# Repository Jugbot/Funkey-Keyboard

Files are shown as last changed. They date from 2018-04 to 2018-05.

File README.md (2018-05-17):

# Funkey-Keyboard ヽ(⌐■_■)ノ♪♬
### A piano with a built-in rhythm game! 
This was a project for New York University's prototyping design class (EG1003) for spring of 2018. The design won the Nick Russo Award and the I2E Award for Innovation.  

The idea behind this prototype was to make learning the piano easier by turning it into a sort of rhythm game. Other similar solutions exist out there such as [pianos that light up the next keys](https://www.smartpiano.com/) or tablet apps that record audio from an existing piano and use it as an input for a a [game-like learning tool](https://www.synthesiagame.com/). This prototype is slightly different in that it integrates 8 leds directly under every key. There is also the possibility of modularity due to the chainable input and display. 

Check out the [video demonstration](https://youtu.be/wlrPzlZg1Dw).

| Implemented | <ul><li>Automatic conversion of midi files to playable songs</li><li>Real time playback</li><li>Pseudo-random color change for differentiating notes</li></ul> |
| :--- | :--- |
| Unimplemented | <ul><li>Tempo must be input manually (bpm variable in code)</li><li>The circuit board for the buttons failed, so input recording and scoring was not able to be tested</li><li>As such the menu with scrolling text is not used in the last release and songs must be set beforehand in-code</li></ul> |

---
## Basic Specs
+ Raspberry Pi 3
+ Python 2

---
## Dependencies:
+ pyllist
+ python-midi
+ adafruit-gpio

---
## Hardware
I used the [ws2811 addressable rgb led string](http://a.co/irZiaNd) as a display.

For the inputs I decided to use [mcp23017 io port expander](https://www.adafruit.com/product/732) to demonstrate the possibility of modularity. 

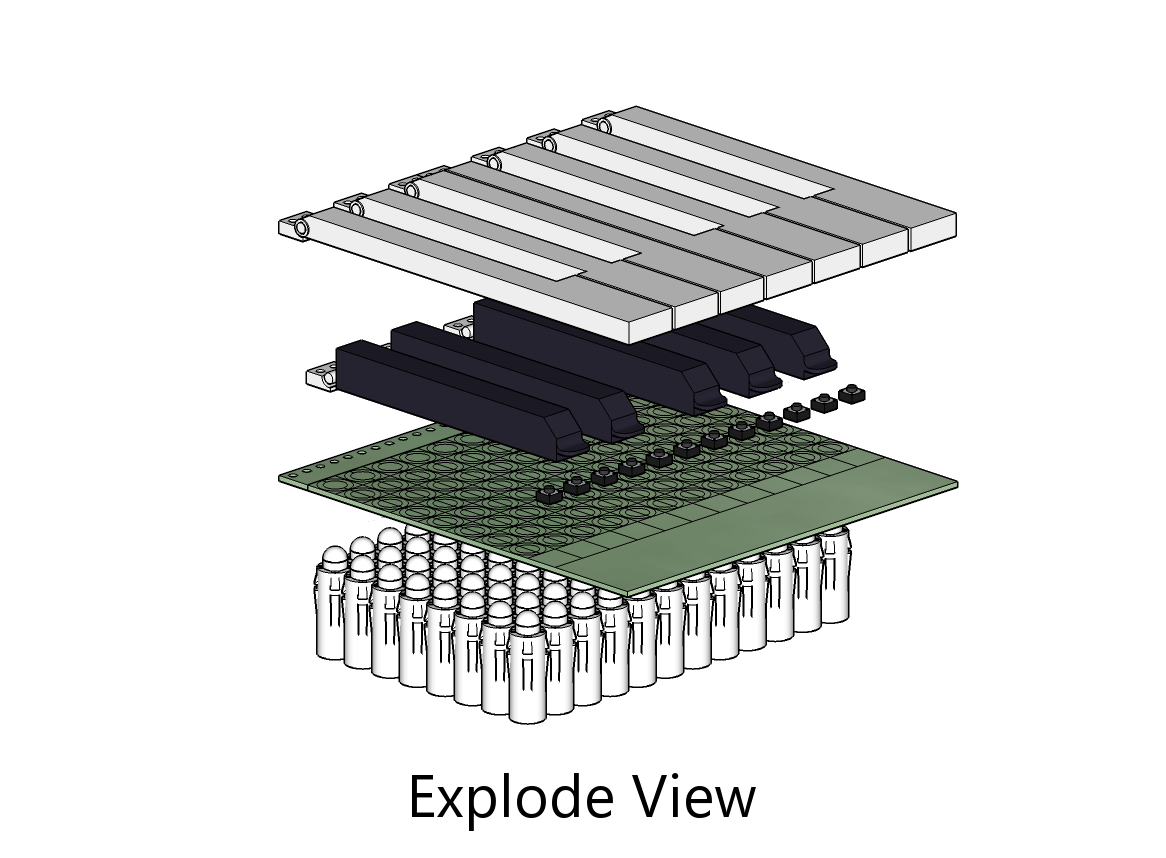
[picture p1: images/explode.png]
Image of ortho explode view


Button Input/ LED Mount | Electrical Schematic 
----------------------- | -------------------- 
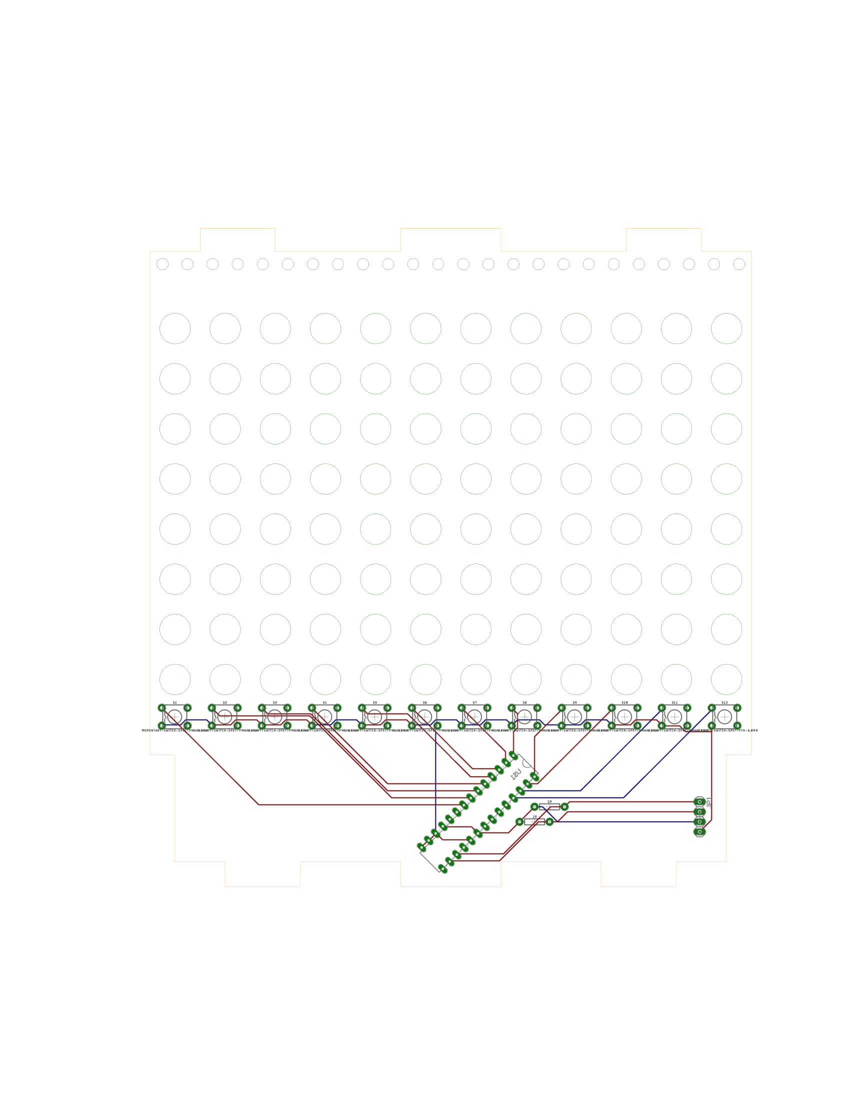
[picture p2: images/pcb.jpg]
Image of pcb board
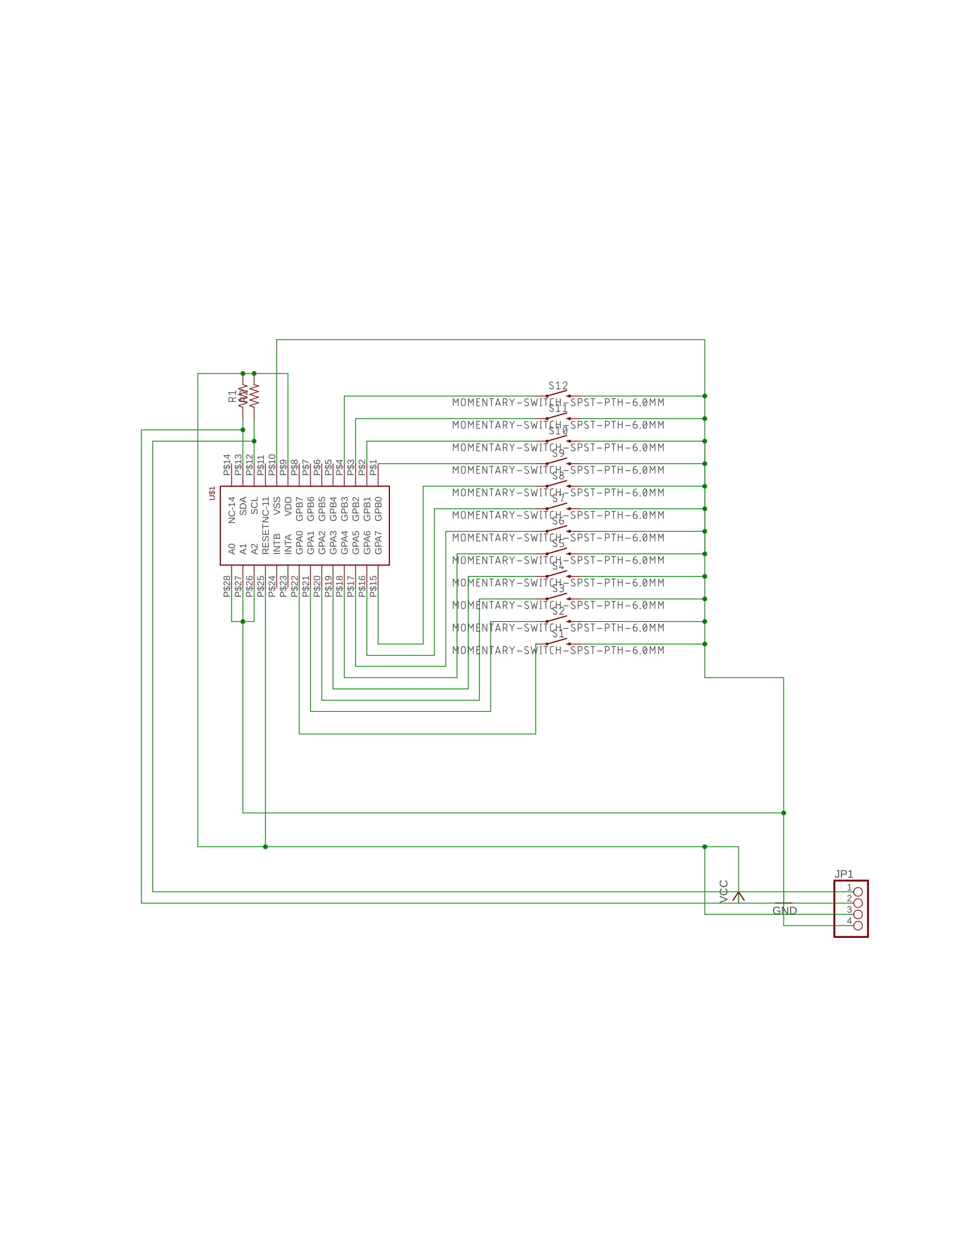
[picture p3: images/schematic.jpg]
Image of electrical schematic
 |

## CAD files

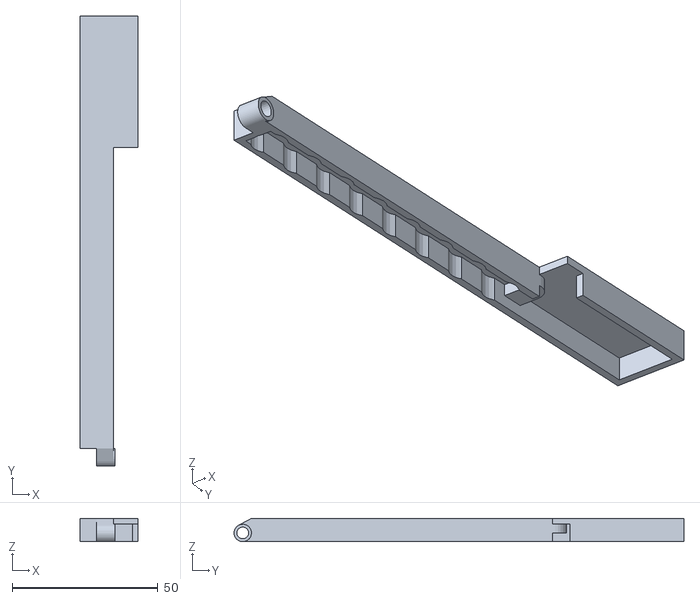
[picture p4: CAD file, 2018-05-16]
Technical Files/resin prints/ekey.stl
20.0 x 154.2 x 8.00

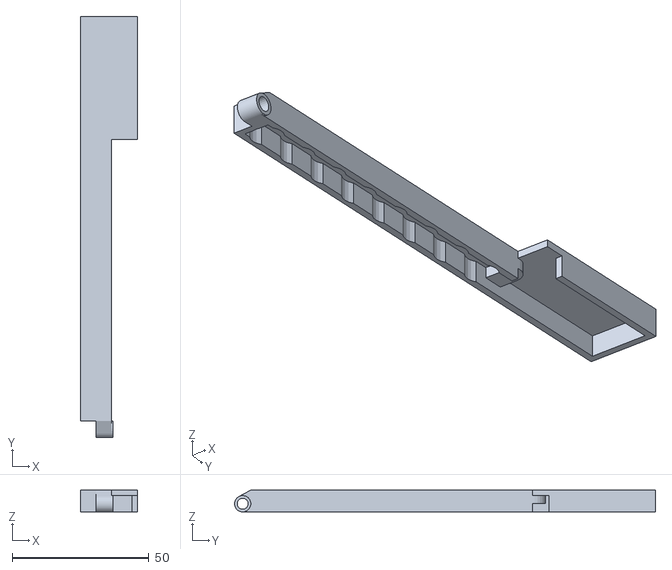
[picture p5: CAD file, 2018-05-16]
Technical Files/resin prints/bkey.stl
21.0 x 154.2 x 8.00

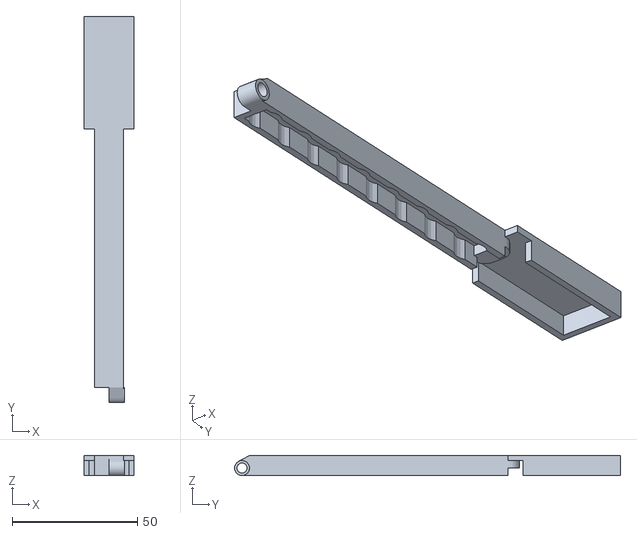
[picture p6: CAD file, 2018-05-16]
Technical Files/resin prints/dkey.stl
20.0 x 154.2 x 8.00

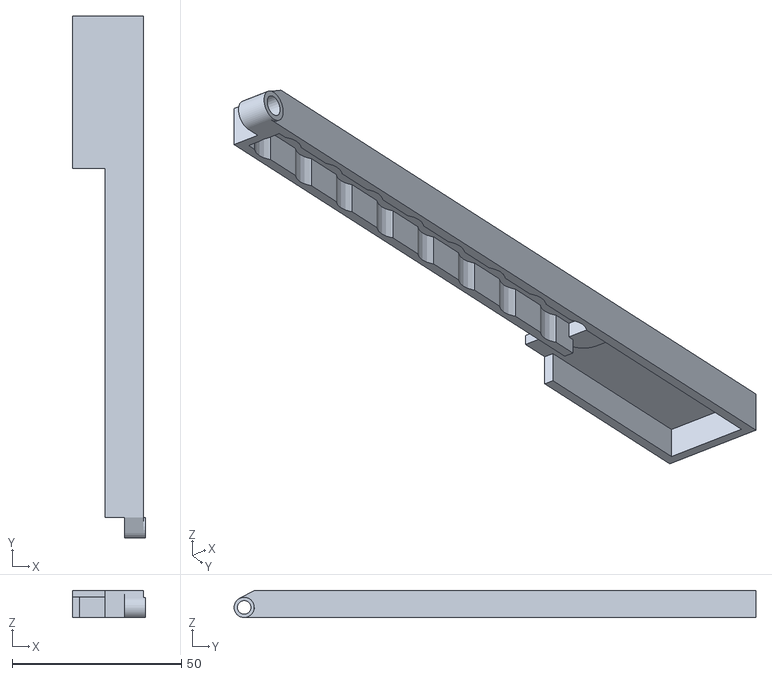
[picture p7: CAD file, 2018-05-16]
Technical Files/resin prints/fkey.stl
21.6 x 154.2 x 8.00

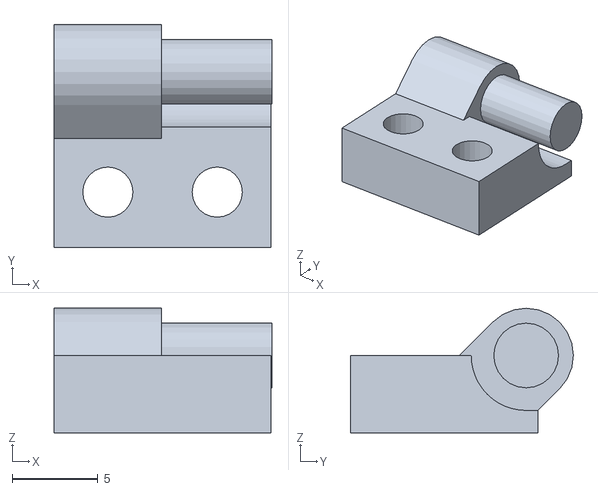
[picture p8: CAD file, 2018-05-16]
Technical Files/resin prints/hinge.stl
12.7 x 13.0 x 7.25

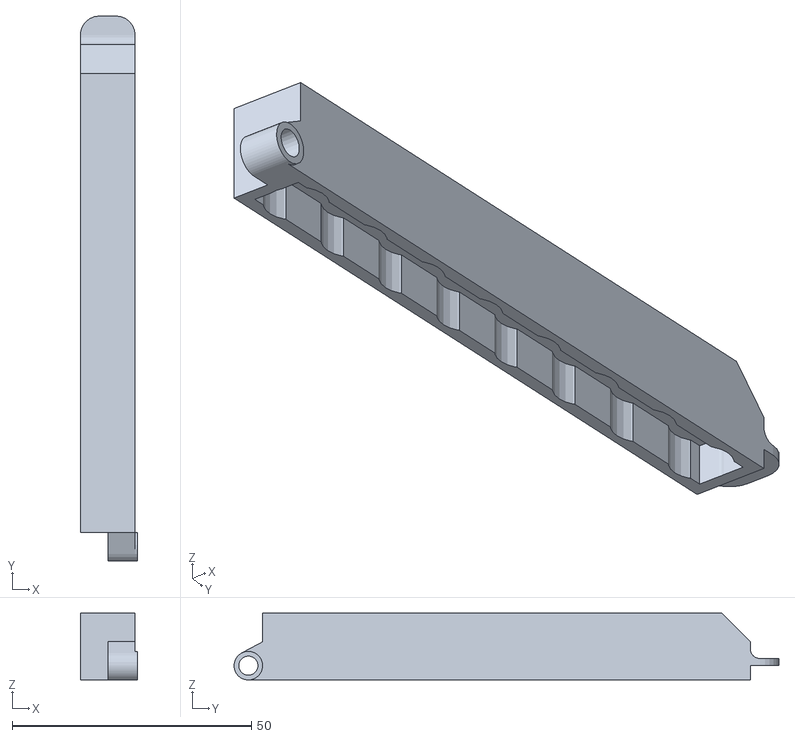
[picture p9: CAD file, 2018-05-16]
Technical Files/resin prints/sharpkey.stl
12.0 x 113.9 x 14.0

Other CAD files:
Technical Files/resin prints/gkey.stl
Technical Files/resin prints/ckey.stl
Technical Files/resin prints/akey.stl

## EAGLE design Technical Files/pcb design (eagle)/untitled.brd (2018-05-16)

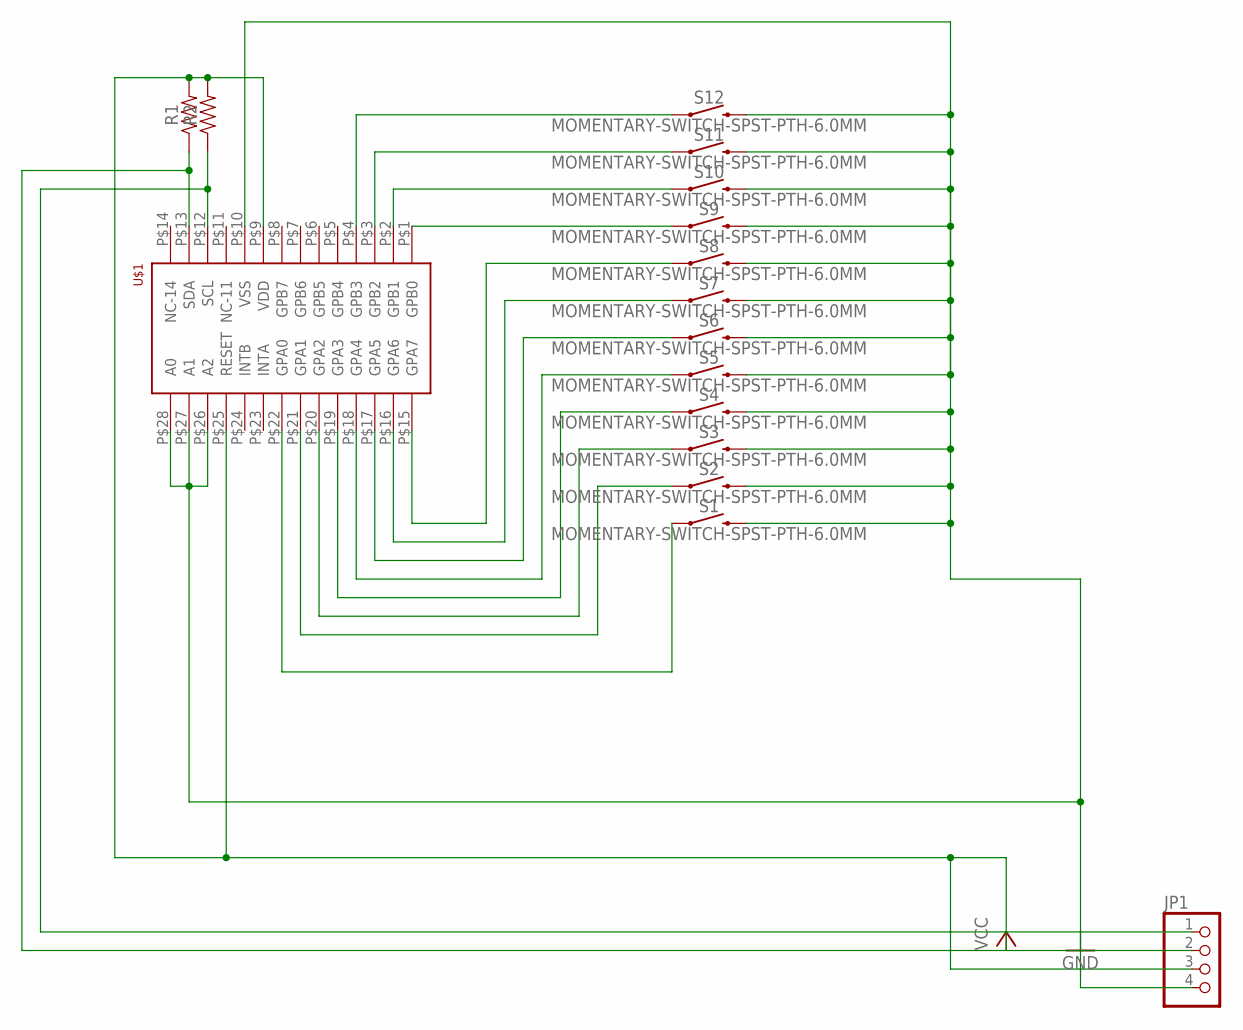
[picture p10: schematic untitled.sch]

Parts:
JP1: PINHD-1X4; 1X04
R1, R2: AXIAL-0.3
S1, S2, S3, S4, S5, S6, S7, S8, S9, S10, S11, S12: MOMENTARY-SWITCH-SPST-PTH-6.0MM; TACTILE_SWITCH_PTH_6.0MM
U$1: MCP23017-E/SP; DIP28

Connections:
GND: JP1.4, S1.3 (2), S2.3 (2), S3.3 (2), S4.3 (2), S5.3 (2), S6.3 (2), S7.3 (2), S8.3 (2), S9.3 (2), S10.3 (2), S11.3 (2), S12.3 (2), U$1.P$10 (VSS), U$1.P$26 (A2), U$1.P$27 (A1), U$1.P$28 (A0)
unnamed: S1.1, U$1.P$22 (GPA0)
unnamed: S2.1, U$1.P$21 (GPA1)
unnamed: S3.1, U$1.P$20 (GPA2)
unnamed: S4.1, U$1.P$19 (GPA3)
unnamed: S5.1, U$1.P$18 (GPA4)
unnamed: S6.1, U$1.P$17 (GPA5)
unnamed: S7.1, U$1.P$16 (GPA6)
unnamed: S8.1, U$1.P$15 (GPA7)
unnamed: S9.1, U$1.P$1 (GPB0)
unnamed: S10.1, U$1.P$2 (GPB1)
unnamed: S11.1, U$1.P$3 (GPB2)
unnamed: S12.1, U$1.P$4 (GPB3)
unnamed: JP1.2, R1.P$1 (1), U$1.P$13 (SDA)
unnamed: JP1.1, R2.P$1 (1), U$1.P$12 (SCL)
VCC: JP1.3, R1.P$2 (2), R2.P$2 (2), U$1.P$9 (VDD), U$1.P$25 (RESET)

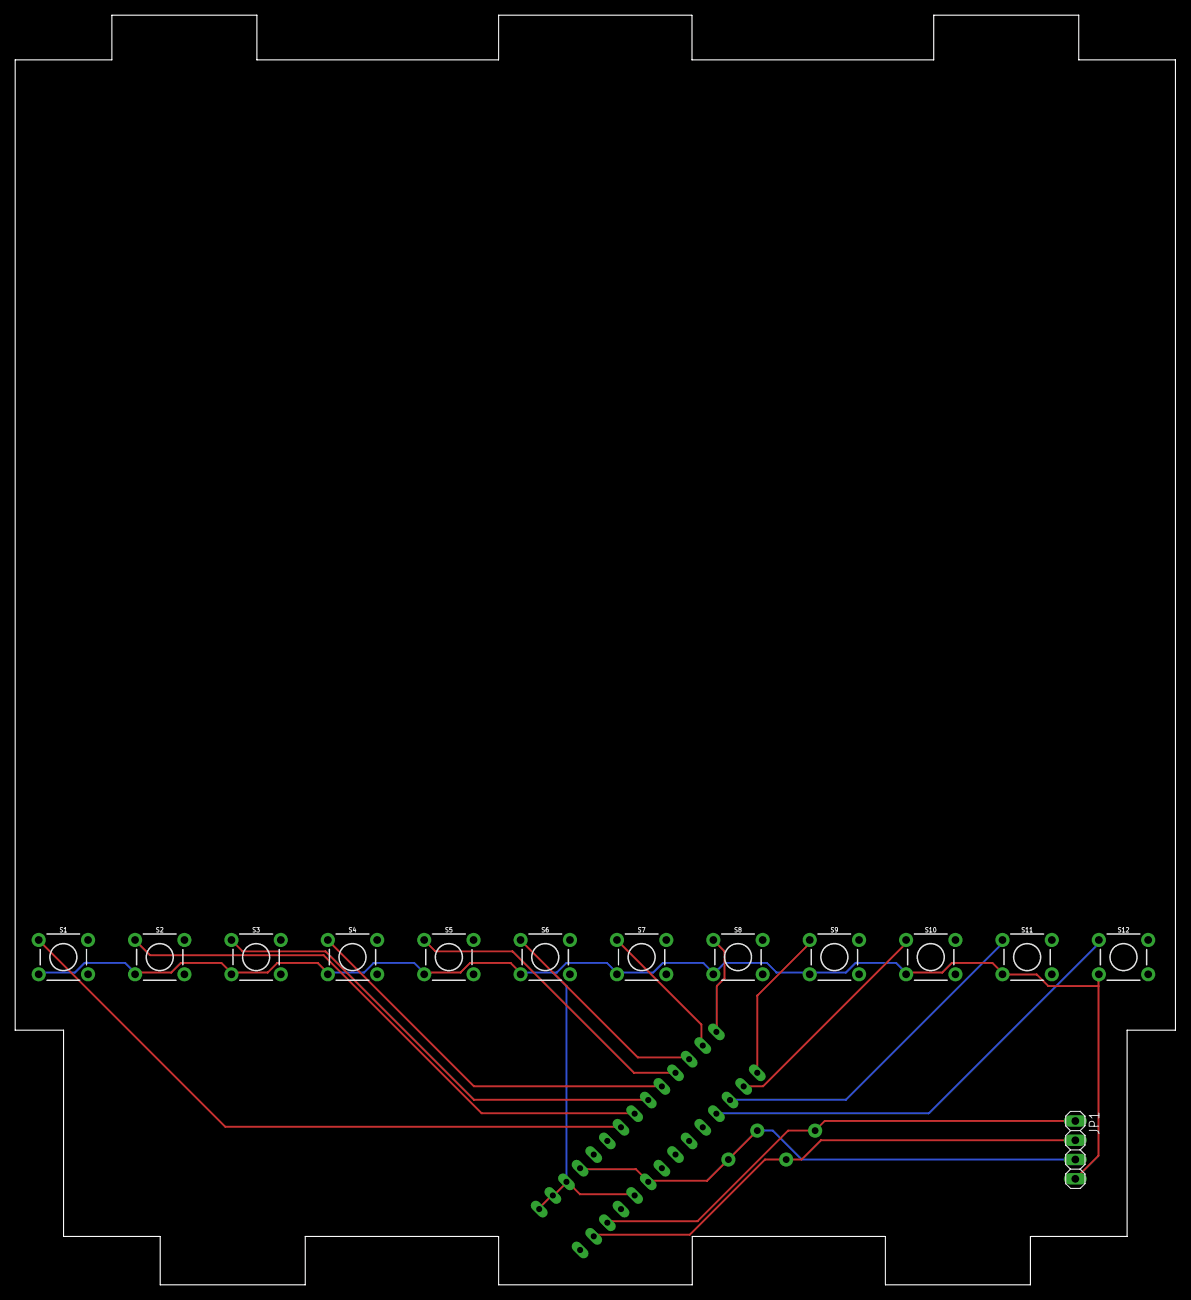
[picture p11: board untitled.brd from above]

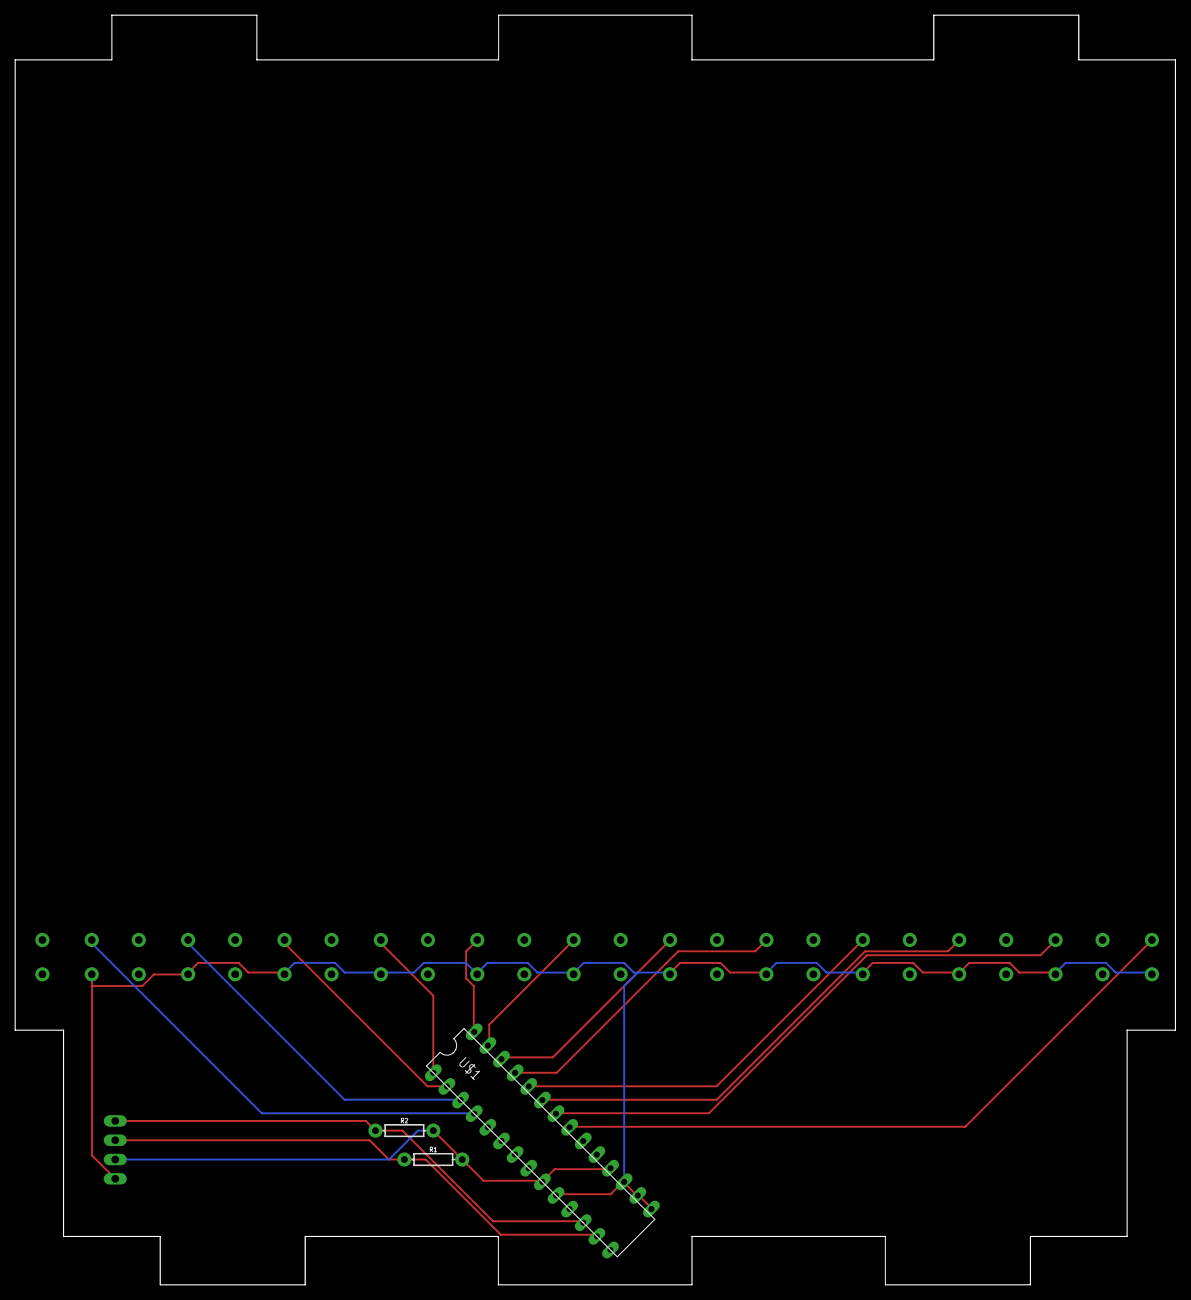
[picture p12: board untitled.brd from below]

Board: 2 copper layers, 152.9 x 167.3 mm, 16 parts (3 on the bottom side), 16 nets.

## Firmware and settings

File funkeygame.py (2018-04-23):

#!/usr/bin/env python
# rhythm game using ws2811 rgb leds
import math
import os
import time
import colorsys
from random import seed, random
from multiprocessing import Process, Queue

import Adafruit_GPIO as GPIO
import MCP230xx
import midi
from scrollingtext import LEDText
from neopixel import *
from pyllist import dllist
import vlc

# Set the port expander global variable
#mcp = MCP230xx.MCP23017()

# Set pins 0-11 to output and pullup(you can set pins 0..15 this way)
for i in xrange(12):
    pass
    #mcp.setup(i, GPIO.IN)
    #mcp.pullup(i, True)

# Seed random
seed(time.time())

# LED strip configuration:
LED_COUNT = 96  # Number of LED pixels.
LED_PIN = 18  # GPIO pin connected to the pixels (must support PWM!).
LED_FREQ_HZ = 800000  # LED signal frequency in hertz (usually 800khz)
LED_DMA = 10  # DMA channel to use for generating signal (try 10)
LED_BRIGHTNESS = 64  # Set to 0 for darkest and 255 for brightest
# True to invert the signal (when using NPN transistor level shift)
LED_INVERT = False
# Menu select buttons indexes
LEFT = 0
SELECT = 1
RIGHT = 2
# three seconds before song starts
START_DELAY = 3.0


def main(strip):

    # Get midi file from menu select
    # midifile = songselectmenu(strip)
    
    path = os.path.join(os.getcwd(), "MidFiles")
    file = os.path.splitext(os.listdir(path)[0])[0]
    midifile = os.path.join(path, file + ".mid")
    mp3file = os.path.join(path, file + ".mp3")

    # read midi file and convert from relative time to absolute
    pattern = midi.read_midifile(midifile)
    pattern.make_ticks_abs()

    # convert beats per minute to seconds per LED
    bpm = 120.0
    spl = 60.0 / bpm / 2

    # convert midi events into an easier to read format
    notes = list(convertPattern(pattern, bpm))
    notes.sort()

    result = Queue()
    starttime = time.time() + START_DELAY
    # input loop
    #input_thread = Process(target=inputloop, args=(notes, starttime, result))
    #input_thread.start()
    # render loop
    
    playsongmp3(mp3file)
    renderloop(notes, spl, strip, starttime)
    
    #input_thread.join()

    #end
    resetall(strip)
    strip.show()
    
def playsongmp3(url):
    p = vlc.MediaPlayer(url)
    p.play()

def inputloop(args):
    notes, starttime, result = args
    perfect_tolerance = 0.1 #radial tolerance of hitting the note perfectly
    hit_tolerance = 0.5 #tolerance where hitting the key counts as hitting the note
    last_note = notes[-1][0]
    presses = []
    score = 0
    b_state = [0] * 12
    gpio_i = range(12)
    while time.time()-starttime < last_note + hit_tolerance:
        for b_i in gpio_i:
            state = True#mcp.input(b_i)
            if state != b_state[b_i]:
                # ( time, button index, state <begin or end> )
                presses.append((time.time()-starttime, b_i, state))
                b_state[b_i] = state
    # song ends calc score out of 10000
    note_ind = 0
    last_possible = None
    for press in presses:
        while press[0] < notes[note_ind][0] + hit_tolerance:
            if press[0] < notes[note_ind][0] - hit_tolerance:
                last_possible = note_ind
            if press[2] == notes[note_ind][2] \
                    and press[1] == notes[note_ind][1]\
                    and -hit_tolerance < press[0] - notes[note_ind][0] < hit_tolerance:
                if -perfect_tolerance < press[0] - notes[note_ind][0] < perfect_tolerance:
                    score += 1
                note_ind = last_possible
                break
            note_ind += 1



    result.put(score/len(notes)*10000)

def renderloop(notes, spl, strip, starttime):
    # local variables for rendering
    renderlist = dllist()
    i = 0
    while i < len(notes) or len(renderlist):
        # print(i)
        while i < len(notes) and notes[i][0] < (time.time() - starttime) + spl * 8:  # render one bar before press (one strip of LEDs)
            # print(notes[i][0], time.time() - starttime)
            if notes[i][2] in range(midi.NOTE_NAME_MAP_SHARP['C_5'], midi.NOTE_NAME_MAP_SHARP['C_6']):
                renderlist.append(
                    Note(strip, notes[i], starttime, spl))  # TODO: might lag if notes are faster than it can render!
            i += 1
        for node in renderlist.iternodes():
            if not node.value.updateNote():  # rendersNote and returns whether or not note is still within scope
                renderlist.remove(node)
        # print([strip.getPixelColor(x) for x in xrange(strip.numPixels())])
        strip.show()



class Note:
    def __init__(self, strip, data, starttime, spl):
        self.strip = strip
        self.start, self.stop, self.pitch = data
        self.offset = self.pitch % 12 * 8  # 0-95
        self.flipped = (self.pitch % 2 == 0)  # the hardware leds flip orientation every eight
        if self.offset > strip.numPixels() - 8:  # remove
            self.offset -= strip.numPixels() - strip.numPixels() % 8
        self.start += starttime  # start of note press
        self.stop += starttime  # end of note press
        self.spl = spl  # seconds per led (one led = one eighth note or 1/2 beat)
        # Random color per note idea (unfinished)
        rcol = random()
        r,g,b = [int(256*i) for i in colorsys.hls_to_rgb(rcol,0.5,1.0)] 
        self.color = Color(r, g, b)
        self.color = Color(255, 255, 255)
        # used by rendering
        self.laststart = 7
        self.laststop = 7
        # dubugging?
        self.name = midi.NOTE_NAMES[self.pitch % 12]
        # print(self.name)

    # controls the LEDs on a designated 8-LED strip
    def updateNote(self):
        if self.stop < time.time():  # draw is done and should be removed
            return False
        if self.start > time.time() + self.spl * 8:  # not ready to draw yet
            return True

        self.renderLED(self.start, self.laststart, self.color, True)
        self.renderLED(self.stop, self.laststop, 0, False)

        return True

    # render LEDs
    def renderLED(self, timestart, lastnote, color, leading):
        startLED = (timestart - time.time()) / self.spl
        absLED = int(math.ceil(startLED))  # absolute led index, where led is at full intensity
        remLED = absLED - startLED  # remainder led, where led is at partial intensity
        if not leading:
            remLED = 1 - remLED  # inverse remainder if it is not part of the leading end of lights
        if startLED < 0:  # if the beginning of the note has passed but the ending has not
            if lastnote < 0:
                return
            absLED = 0

        for ledind in xrange(absLED, lastnote + 1):
            if not self.flipped:
                self.strip.setPixelColor(7 - ledind + self.offset, color)
            else:
                self.strip.setPixelColor(ledind + self.offset, color)

        if absLED > 0:
            cval = int(256 * remLED)
            if not self.flipped:
                self.strip.setPixelColor(7 - (absLED - 1) + self.offset, Color(cval, cval, cval))
            else:
                self.strip.setPixelColor(absLED - 1 + self.offset, Color(cval, cval, cval))

        lastnote = absLED


# BPM to SPT
def secondsPerTick(bpm, res):
    return 60.0 / (bpm * res)


# Converting midi pattern into a more readable format
def convertPattern(pattern, bpm):
    spt = secondsPerTick(bpm, pattern.resolution)
    notestore = dllist()

    def addnotestore(notedata):
        if notedata[2] == False:
            for noteidx in xrange(len(notestore)):
                if notestore[noteidx][2] == True and notestore[noteidx][1] == notedata[1]:
                    note = notestore[noteidx]
                    del notestore[noteidx]
                    yield (note[0] * spt, notedata[0] * spt, note[1])
                    break
            else:
                print("Starting match not found for ", notedata)
        else:
            notestore.append(notedata)

    for track in pattern:
        for event in track:
            if isinstance(event, midi.events.NoteOnEvent):
                if event.data[1] == 0:
                    for x in addnotestore((event.tick, event.data[0], False)):
                        yield x
                else:
                    for x in addnotestore((event.tick, event.data[0], True)):
                        yield x
            elif isinstance(event, midi.events.NoteOffEvent):
                for x in addnotestore((event.tick, event.data[0], False)):
                    yield x
                    # Wipe strip


def resetall(strip):
    for i in xrange(strip.numPixels()):
        strip.setPixelColor(i, Color(0, 0, 0))
    strip.show()

def wheel(pos):
	if pos < 85:
		return Color(pos * 3, 255 - pos * 3, 0)
	elif pos < 170:
		pos -= 85
		return Color(255 - pos * 3, 0, pos * 3)
	else:
		pos -= 170
		return Color(0, pos * 3, 255 - pos * 3)

# Menu, shows scrolling text .split(".")[0]
def songselectmenu(strip):
    path = os.path.join(os.getcwd(), "MidFiles")
    mid_files = os.listdir(path)

    index = 0
    resetall(strip)

    ledtext = LEDText("Select A Song!  ", 12, 8)
    canend = False
    while True:
        ledtext.nextview()
        for strip_i, led in zip(xrange(strip.numPixels()), ledtext):
            if led:
                strip.setPixelColor(strip_i, wheel((strip_i - int(time.time()*100)) & 255))
            else:
                strip.setPixelColor(strip_i, 0)
        strip.show()
        time.sleep(0.05)

        left = True#mcp.input(LEFT)
        select = True#mcp.input(SELECT)
        right = True#mcp.input(RIGHT)

        if (left):
            index = (index - 1) % (len(mid_files))
            canend = True
        elif (right):
            index = (index + 1) % (len(mid_files))
            canend = True
        elif select and canend:
            return os.path.join(path, mid_files[index])



# DEBUG
def lighttest(strip):
    for i in xrange(strip.numPixels()):
        strip.setPixelColor(i, Color(255, 255, 255))
    strip.show()
    time.sleep(1.0)


if __name__ == '__main__':
    # Create NeoPixel object with appropriate configuration.
    strip = Adafruit_NeoPixel(LED_COUNT, LED_PIN, LED_FREQ_HZ, LED_DMA, LED_INVERT, LED_BRIGHTNESS)
    # Intialize the library (must be called once before other functions).
    strip.begin()
    try:
        while True:
            main(strip)
    except KeyboardInterrupt:
        print("W: interrupt received, stopping...")
    finally:
        # clean up
        resetall(strip)

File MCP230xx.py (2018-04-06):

# Copyright (c) 2014 Adafruit Industries
# Author: Tony DiCola
#
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
import Adafruit_GPIO as GPIO
import Adafruit_GPIO.I2C as I2C


class MCP230xxBase(GPIO.BaseGPIO):
    """Base class to represent an MCP230xx series GPIO extender.  Is compatible
    with the Adafruit_GPIO BaseGPIO class so it can be used as a custom GPIO
    class for interacting with device.
    """

    def __init__(self, address, i2c=None, **kwargs):
        """Initialize MCP230xx at specified I2C address and bus number.  If bus
        is not specified it will default to the appropriate platform detected bus.
        """
        # Create I2C device.
        if i2c is None:
            import Adafruit_GPIO.I2C as I2C
            i2c = I2C
        self._device = i2c.get_i2c_device(address, **kwargs)
        # Assume starting in ICON.BANK = 0 mode (sequential access).
        # Compute how many bytes are needed to store count of GPIO.
        self.gpio_bytes = int(math.ceil(self.NUM_GPIO/8.0))
        # Buffer register values so they can be changed without reading.
        self.iodir = [0xFF]*self.gpio_bytes  # Default direction to all inputs.
        self.gppu = [0x00]*self.gpio_bytes  # Default to pullups disabled.
        self.gpio = [0x00]*self.gpio_bytes
        # Write current direction and pullup buffer _last_pos.
        self.write_iodir()
        self.write_gppu()


    def setup(self, pin, value):
        """Set the input or output mode for a specified pin.  Mode should be
        either GPIO.OUT or GPIO.IN.
        """
        self._validate_pin(pin)
        # Set bit to 1 for input or 0 for output.
        if value == GPIO.IN:
            self.iodir[int(pin/8)] |= 1 << (int(pin%8))
        elif value == GPIO.OUT:
            self.iodir[int(pin/8)] &= ~(1 << (int(pin%8)))
        else:
            raise ValueError('Unexpected value.  Must be GPIO.IN or GPIO.OUT.')
        self.write_iodir()


    def output(self, pin, value):
        """Set the specified pin the provided high/low value.  Value should be
        either GPIO.HIGH/GPIO.LOW or a boolean (True = HIGH).
        """
        self.output_pins({pin: value})

    def output_pins(self, pins):
        """Set multiple pins high or low at once.  Pins should be a dict of pin
        name to pin value (HIGH/True for 1, LOW/False for 0).  All provided pins
        will be set to the given values.
        """
        [self._validate_pin(pin) for pin in pins.keys()]
        # Set each changed pin's bit.
        for pin, value in iter(pins.items()):
            if value:
                self.gpio[int(pin/8)] |= 1 << (int(pin%8))
            else:
                self.gpio[int(pin/8)] &= ~(1 << (int(pin%8)))
        # Write GPIO _last_pos.
        self.write_gpio()


    def input(self, pin):
        """Read the specified pin and return GPIO.HIGH/True if the pin is pulled
        high, or GPIO.LOW/False if pulled low.
        """
        return self.input_pins([pin])[0]

    def input_pins(self, pins):
        """Read multiple pins specified in the given list and return list of pin values
        GPIO.HIGH/True if the pin is pulled high, or GPIO.LOW/False if pulled low.
        """
        [self._validate_pin(pin) for pin in pins]
        # Get GPIO _last_pos.
        self.gpio = self._device.readList(self.GPIO, self.gpio_bytes)
        # Return True if pin's bit is set.
        return [(self.gpio[int(pin/8)] & 1 << (int(pin%8))) > 0 for pin in pins]


    def pullup(self, pin, enabled):
        """Turn on the pull-up resistor for the specified pin if enabled is True,
        otherwise turn off the pull-up resistor.
        """
        self._validate_pin(pin)
        if enabled:
            self.gppu[int(pin/8)] |= 1 << (int(pin%8))
        else:
            self.gppu[int(pin/8)] &= ~(1 << (int(pin%8)))
        self.write_gppu()

    def write_gpio(self, gpio=None):
        """Write the specified byte value to the GPIO registor.  If no value
        specified the current buffered value will be written.
        """
        if gpio is not None:
            self.gpio = gpio
        self._device.writeList(self.GPIO, self.gpio)

    def write_iodir(self, iodir=None):
        """Write the specified byte value to the IODIR registor.  If no value
        specified the current buffered value will be written.
        """
        if iodir is not None:
            self.iodir = iodir
        self._device.writeList(self.IODIR, self.iodir)

    def write_gppu(self, gppu=None):
        """Write the specified byte value to the GPPU registor.  If no value
        specified the current buffered value will be written.
        """
        if gppu is not None:
            self.gppu = gppu
        self._device.writeList(self.GPPU, self.gppu)


class MCP23017(MCP230xxBase):
    """MCP23017-based GPIO class with 16 GPIO pins."""
    # Define number of pins and registor addresses.
    NUM_GPIO = 16
    IODIR    = 0x00
    GPIO     = 0x12
    GPPU     = 0x0C

    def __init__(self, address=0x20, **kwargs):
        super(MCP23017, self).__init__(address, **kwargs)


class MCP23008(MCP230xxBase):
    """MCP23008-based GPIO class with 8 GPIO pins."""
    # Define number of pins and registor addresses.
    NUM_GPIO = 8
    IODIR    = 0x00
    GPIO     = 0x09
    GPPU     = 0x06

    def __init__(self, address=0x20, **kwargs):
        super(MCP23008, self).__init__(address, **kwargs)

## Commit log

2018-04-06 Button input and scoring
    Cleaned code and added multiprocessed button input register and scoring for when the song plays.
    Havent tested yet so garunteed not to work.
2018-05-17 images for pcb

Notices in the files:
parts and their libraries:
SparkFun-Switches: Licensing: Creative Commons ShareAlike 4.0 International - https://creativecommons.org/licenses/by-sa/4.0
